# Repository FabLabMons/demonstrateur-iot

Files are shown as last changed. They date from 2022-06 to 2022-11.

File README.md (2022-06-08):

# Click IoT Board
## Purpose
This board aims to provide a starting point for building LTE Cat 1 projects for collecting data from a range of sensors.
These sensors can be connected on the I2C and SPI interfaces via a 4-wires connector.
Sensor boards will be hosted on a separate repository.

## Miscellaneous
We use the open source CAD tool KiCAD to build our boards: https://www.kicad.org/

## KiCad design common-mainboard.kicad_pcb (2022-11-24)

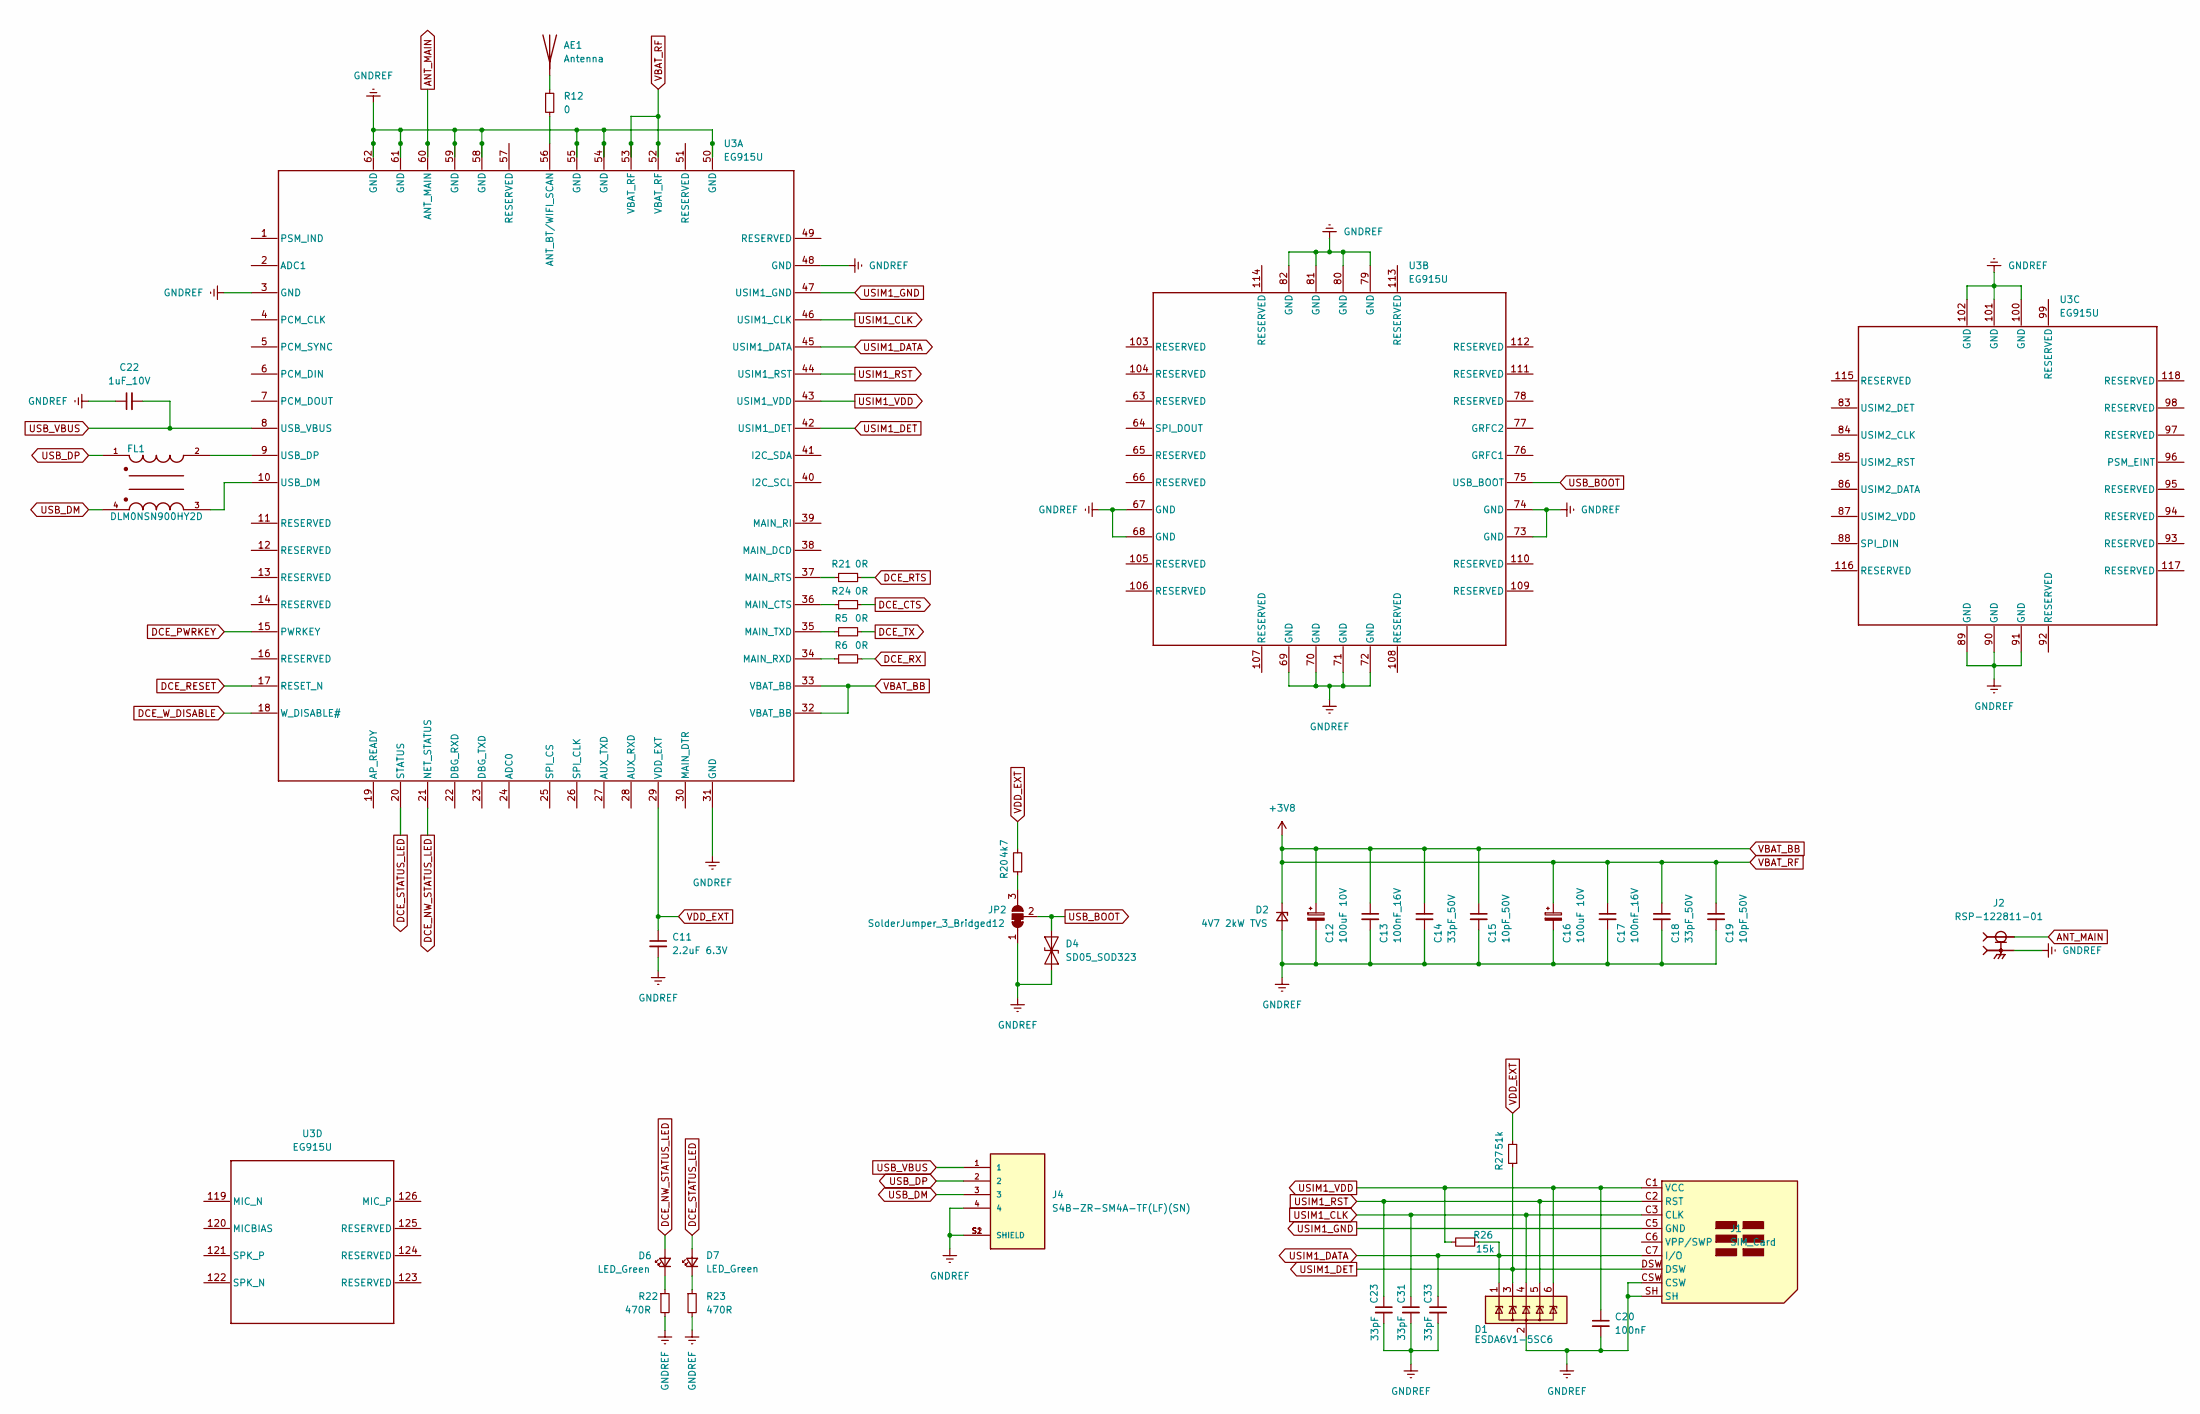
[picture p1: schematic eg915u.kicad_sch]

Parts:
AE1: Antenna; Quectel_YC0010AA
C11: 2.2uF 6.3V; C_0603_1608Metric
C12, C16: 100uF 10V; C_0603_1608Metric
C13, C17: 100nF_16V; C_0402_1005Metric
C14, C18: 33pF_50V; C_0402_1005Metric
C15, C19: 10pF_50V; C_0402_1005Metric
C20: 100nF; C_0402_1005Metric
C22: 1uF_10V; C_0603_1608Metric
C23, C31, C33: 33pF; C_0402_1005Metric
D1: ESDA6V1-5SC6; SOT-23-6
D2: 4V7 2kW TVS; D_SOD-323
D4: SD05_SOD323; D_SOD-323
D6, D7: LED_Green; LED_0805_2012Metric
FL1: DLM0NSN900HY2D; FIL_DLM0NSN900HY2D; PARTREV N/A
J1: SIM_Card; JAE_SIM_Card_SF72S006
J2: RSP-122811-01; SAMTEC_RSP-122811-01; PARTREV H
J4: S4B-ZR-SM4A-TF(LF)(SN); JST_S4B-ZR-SM4A-TF(LF)(SN); PARTREV N/A
JP2: SolderJumper_3_Bridged12; SolderJumper-3_P1.3mm_Bridged12_RoundedPad1.0x1.5mm
R5, R6, R21, R24: 0R; R_0402_1005Metric
R12: 0; R_0402_1005Metric
R20: 4k7; R_0402_1005Metric
R22, R23: 470R; R_0402_1005Metric
R26: 15k; R_0402_1005Metric
R27: 51k; R_0402_1005Metric
U3: EG915U; _AD LIB_EG915U.PcbLib_EG915U

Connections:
ANT_MAIN: J2.1, U3.60 (ANT_MAIN)
DCE_CTS: R24.2; also elsewhere on the board
DCE_NW_STATUS_LED: D6.2 (A), U3.21 (NET_STATUS)
DCE_PWRKEY: U3.15 (PWRKEY); also elsewhere on the board
DCE_RESET: U3.17 (RESET_N); also elsewhere on the board
DCE_RTS: R21.2; also elsewhere on the board
DCE_RX: R6.2; also elsewhere on the board
DCE_STATUS_LED: D7.2 (A), U3.20 (STATUS)
DCE_TX: R5.2; also elsewhere on the board
DCE_W_DISABLE: U3.18 (W_DISABLE#); also elsewhere on the board
GNDREF: C11.2, C12.2, C13.2, C14.2, C15.2, C16.2, C17.2, C18.2, C19.2, C20.2, C22.1, C23.2, C31.2, C33.2, D1.2 (GND), D2.2 (A), D4.2 (A2), J1.CSW, J1.SH, J2.G1, J2.G2, J4.4, J4.S1 (SHIELD), J4.S2 (SHIELD), JP2.1 (A), R22.2, R23.2, U3.3 (GND), U3.31 (GND), U3.48 (GND), U3.50 (GND), U3.54 (GND), U3.55 (GND), U3.58 (GND), U3.59 (GND), U3.61 (GND), U3.62 (GND), U3.67 (GND), U3.68 (GND), U3.69 (GND), U3.70 (GND), U3.71 (GND), U3.72 (GND), U3.73 (GND), U3.74 (GND), U3.79 (GND), U3.80 (GND), U3.81 (GND), U3.82 (GND), U3.89 (GND), U3.90 (GND), U3.91 (GND), U3.100 (GND), U3.101 (GND), U3.102 (GND); also elsewhere on the board
unnamed: AE1.1 (A), R12.1
unnamed: D6.1 (K), R22.1
unnamed: D7.1 (K), R23.1
unnamed: FL1.2, U3.9 (USB_DP)
unnamed: FL1.3, U3.10 (USB_DM)
unnamed: JP2.3 (B), R20.1
unnamed: R5.1, U3.35 (MAIN_TXD)
unnamed: R6.1, U3.34 (MAIN_RXD)
unnamed: R12.2, U3.56 (ANT_BT/WIFI_SCAN)
unnamed: R21.1, U3.37 (MAIN_RTS)
unnamed: R24.1, U3.36 (MAIN_CTS)
USB_BOOT: D4.1 (A1), JP2.2 (C), U3.75 (USB_BOOT)
USB_DM: FL1.4, J4.3
USB_DP: FL1.1, J4.2
USB_VBUS: C22.2, J4.1, U3.8 (USB_VBUS)
USIM1_CLK: C31.1, D1.4 (IO3), J1.C3 (CLK), U3.46 (USIM1_CLK)
USIM1_DATA: C33.1, D1.1 (IO1), J1.C7 (I/O), R26.1, U3.45 (USIM1_DATA)
USIM1_DET: D1.3 (IO2), J1.DSW, R27.1, U3.42 (USIM1_DET)
USIM1_GND: J1.C5 (GND), U3.47 (USIM1_GND)
USIM1_RST: C23.1, D1.5 (IO4), J1.C2 (RST), U3.44 (USIM1_RST)
USIM1_VDD: C20.1, D1.6 (IO5), J1.C1 (VCC), R26.2, U3.43 (USIM1_VDD)
VBAT_BB: C12.1, C13.1, C14.1, C15.1, C16.1, C17.1, C18.1, C19.1, D2.1 (K), U3.32 (VBAT_BB), U3.33 (VBAT_BB), U3.52 (VBAT_RF), U3.53 (VBAT_RF); also elsewhere on the board
VDD_EXT: C11.1, R20.2, R27.2, U3.29 (VDD_EXT); also elsewhere on the board

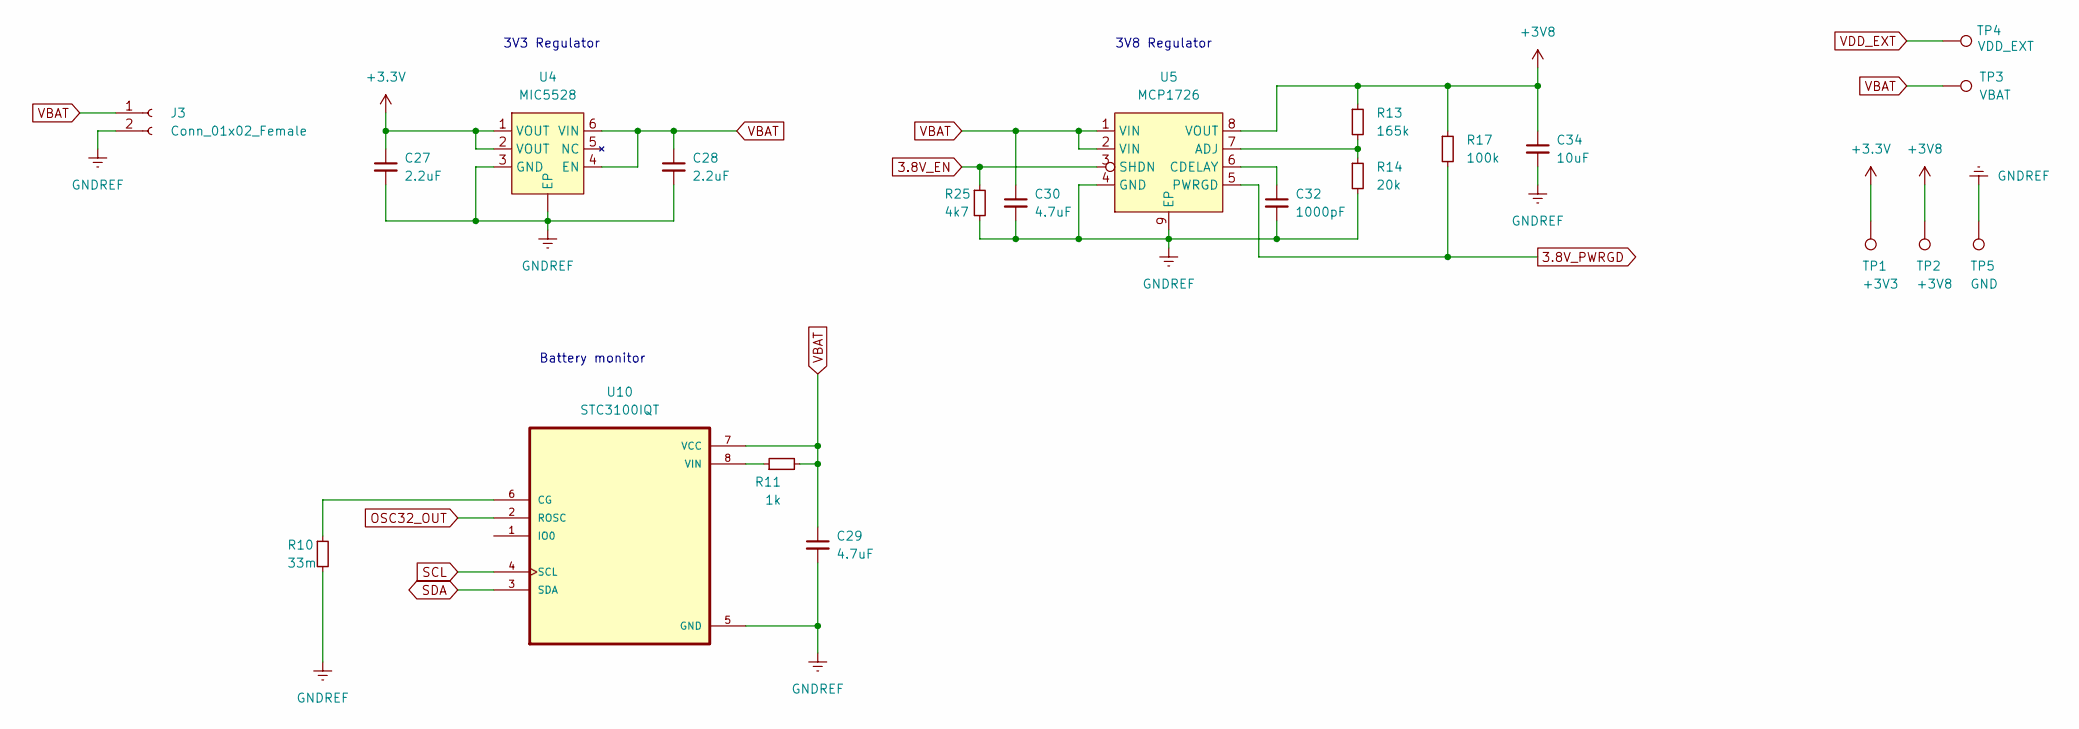
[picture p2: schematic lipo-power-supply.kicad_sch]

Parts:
C27, C28: 2.2uF; C_0603_1608Metric
C29, C30: 4.7uF; C_0603_1608Metric
C32: 1000pF; C_0201_0603Metric
C34: 10uF; C_0603_1608Metric
J3: Conn_01x02_Female; JST_PH_B2B-PH-SM4-TB_1x02-1MP_P2.00mm_Vertical
R10: 33m; R_0402_1005Metric
R11: 1k; R_0402_1005Metric
R13: 165k; R_0402_1005Metric
R14: 20k; R_0402_1005Metric
R17: 100k; R_0402_1005Metric
R25: 4k7; R_0402_1005Metric
TP1: +3V3; TestPoint_Pad_D1.5mm
TP2: +3V8; TestPoint_Pad_D1.5mm
TP3: VBAT; TestPoint_Pad_D1.5mm
TP4: VDD_EXT; TestPoint_Pad_D1.5mm
TP5: GND; TestPoint_Pad_D1.5mm
U4: MIC5528; DFN-6-1EP_1.2x1.2mm_P0.4mm_EP0.3x0.94mm_PullBack
U5: MCP1726; DFN-8-1EP_3x3mm_P0.65mm_EP1.55x2.4mm
U10: STC3100IQT; DFN-8-1EP_3x3mm_P0.5mm_EP1.65x2.38mm

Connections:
3.8V_EN: R25.1, U5.3 (SHDN); also elsewhere on the board
3.8V_PWRGD: R17.2, U5.5 (PWRGD); also elsewhere on the board
+3V3: C27.1, TP1.1, U4.1 (VOUT), U4.2 (VOUT); also elsewhere on the board
GNDREF: C27.2, C28.2, C29.2, C30.2, C32.2, C34.2, J3.2, R10.2, R14.2, R25.2, TP5.1, U4. (EP), U4.3 (GND), U5.4 (GND), U5.9 (EP), U10.5 (GND); also elsewhere on the board
unnamed: C32.1, U5.6 (CDELAY)
unnamed: R10.1, U10.6 (CG)
unnamed: R11.1, U10.8 (VIN)
unnamed: R13.2, R14.1, U5.7 (ADJ)
OSC32_OUT: U10.2 (ROSC); also elsewhere on the board
SCL: U10.4 (SCL); also elsewhere on the board
SDA: U10.3 (SDA); also elsewhere on the board
VBAT: C28.1, C29.1, C30.1, J3.1, R11.2, TP3.1, U4.4 (EN), U4.6 (VIN), U5.1 (VIN), U5.2 (VIN), U10.7 (VCC)
VBAT_BB: C34.1, R13.1, R17.1, TP2.1, U5.8 (VOUT); also elsewhere on the board
VDD_EXT: TP4.1; also elsewhere on the board

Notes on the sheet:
Battery monitor
3V8 Regulator
3V3 Regulator

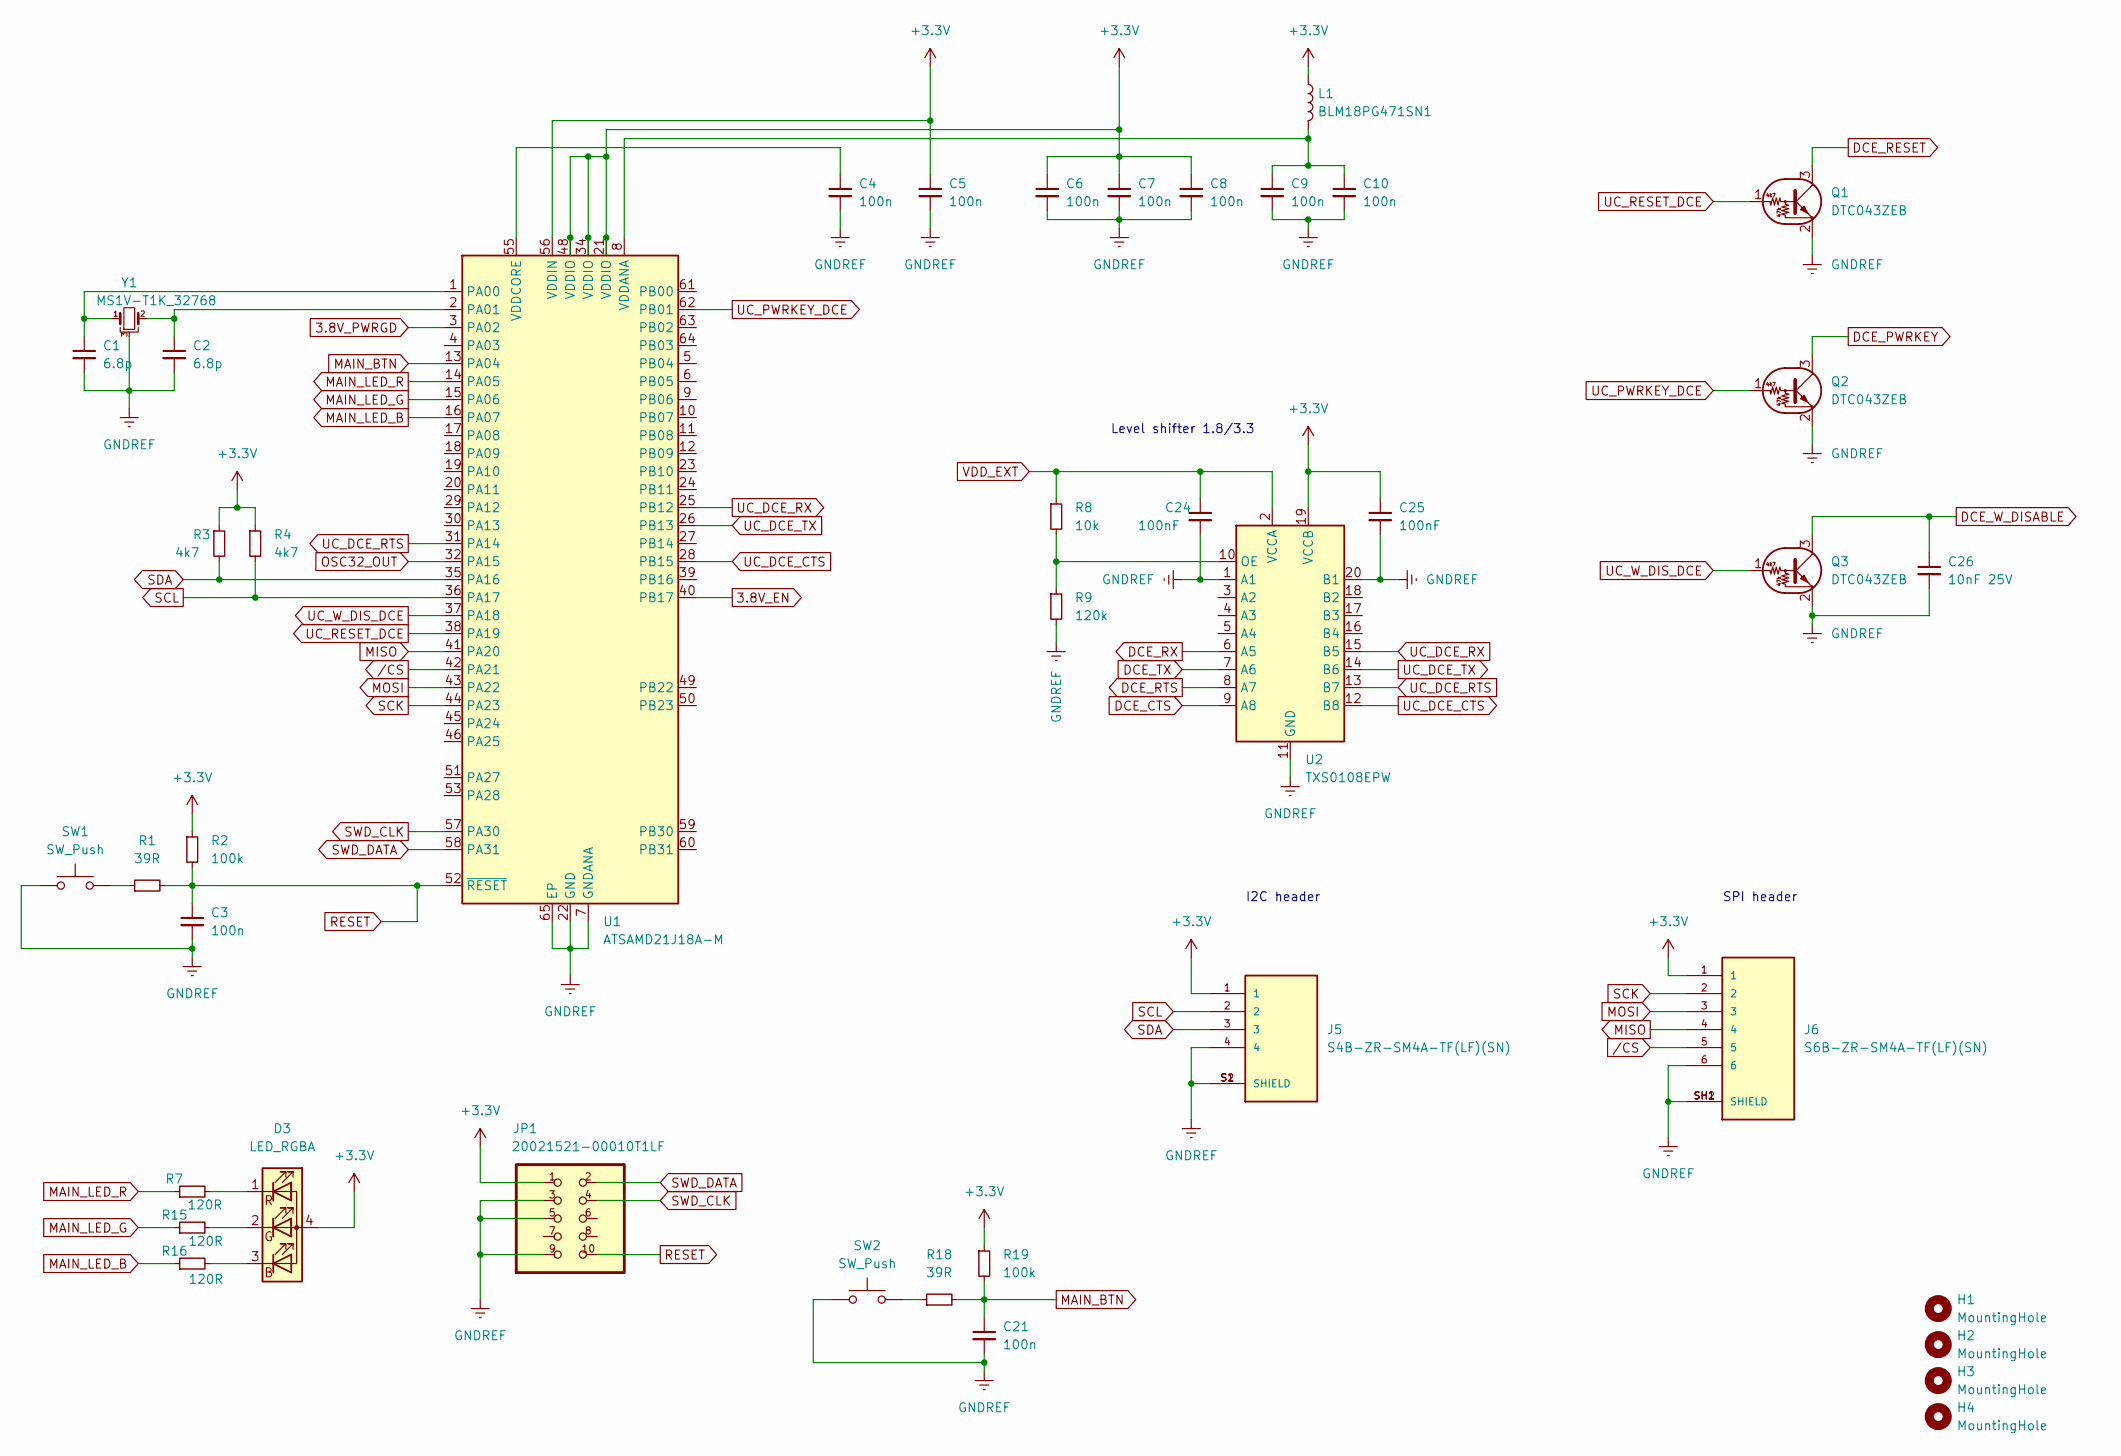
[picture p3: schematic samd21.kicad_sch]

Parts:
C1, C2: 6.8p; C_0402_1005Metric
C3, C4, C5, C6, C7, C8, C9, C10, C21: 100n; C_0402_1005Metric
C24, C25: 100nF; C_0402_1005Metric
C26: 10nF 25V; C_0402_1005Metric
D3: LED_RGBA; LED_RGB_Wuerth-PLCC4_3.2x2.8mm_150141M173100
H1, H2, H3, H4: MountingHole; MountingHole_3.2mm_M3
J5: S4B-ZR-SM4A-TF(LF)(SN); JST_S4B-ZR-SM4A-TF(LF)(SN); PARTREV N/A
J6: S6B-ZR-SM4A-TF(LF)(SN); JST_S6B-ZR-SM4A-TF(LF)(SN)
JP1: 20021521-00010T1LF
L1: BLM18PG471SN1; C_0603_1608Metric
Q1, Q2, Q3: DTC043ZEB; SOT-416
R1, R18: 39R; R_0402_1005Metric
R2, R19: 100k; R_0402_1005Metric
R3, R4: 4k7; R_0402_1005Metric
R7, R15, R16: 120R; R_0402_1005Metric
R8: 10k; R_0402_1005Metric
R9: 120k; R_0402_1005Metric
SW1, SW2: SW_Push; SW_SPST_CK_KXT3
U1: ATSAMD21J18A-M; QFN-64-1EP_9x9mm_P0.5mm_EP4.7x4.7mm
U2: TXS0108EPW; TSSOP-20_4.4x6.5mm_P0.65mm
Y1: MS1V-T1K_32768; Crystal_SMD_MicroCrystal_MS1V-T1K

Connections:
3.8V_EN: U1.40 (PB17); also elsewhere on the board
3.8V_PWRGD: U1.3 (PA02); also elsewhere on the board
+3V3: C5.1, C6.1, C7.1, C8.1, C25.1, D3.4 (A), J5.1, J6.1, JP1.1, L1.1, R2.1, R3.1, R4.1, R19.1, U1.21 (VDDIO), U1.34 (VDDIO), U1.48 (VDDIO), U1.56 (VDDIN), U2.19 (VCCB); also elsewhere on the board
DCE_CTS: U2.9 (A8); also elsewhere on the board
DCE_PWRKEY: Q2.3 (C); also elsewhere on the board
DCE_RESET: Q1.3 (C); also elsewhere on the board
DCE_RTS: U2.8 (A7); also elsewhere on the board
DCE_RX: U2.6 (A5); also elsewhere on the board
DCE_TX: U2.7 (A6); also elsewhere on the board
DCE_W_DISABLE: C26.1, Q3.3 (C); also elsewhere on the board
GNDREF: C1.2, C2.2, C3.2, C4.2, C5.2, C6.2, C7.2, C8.2, C9.2, C10.2, C21.2, C24.2, C25.2, C26.2, J5.4, J5.S1 (SHIELD), J5.S2 (SHIELD), J6.6, J6.SH1 (SHIELD), J6.SH2 (SHIELD), JP1.3, JP1.5, JP1.9, Q1.2 (E), Q2.2 (E), Q3.2 (E), R9.2, SW1.1, SW2.1, U1.7 (GNDANA), U1.22 (GND), U1.33 (GND), U1.47 (GND), U1.54 (GND), U1.65 (EP), U2.1 (A1), U2.11 (GND), U2.20 (B1), Y1.3; also elsewhere on the board
MAIN_BTN: C21.1, R18.2, R19.2, U1.13 (PA04)
MAIN_LED_B: R16.1, U1.16 (PA07)
MAIN_LED_G: R15.1, U1.15 (PA06)
MAIN_LED_R: R7.1, U1.14 (PA05)
MISO: J6.4, U1.41 (PA20)
MOSI: J6.3, U1.43 (PA22)
unnamed: C1.1, U1.1 (PA00), Y1.1
unnamed: C2.1, U1.2 (PA01), Y1.2
unnamed: C4.1, U1.55 (VDDCORE)
unnamed: C9.1, C10.1, L1.2, U1.8 (VDDANA)
unnamed: D3.1 (RK), R7.2
unnamed: D3.2 (GK), R15.2
unnamed: D3.3 (BK), R16.2
unnamed: R1.1, SW1.2
unnamed: R8.2, R9.1, U2.10 (OE)
unnamed: R18.1, SW2.2
OSC32_OUT: U1.32 (PA15); also elsewhere on the board
RESET: C3.1, JP1.10, R1.2, R2.2, U1.52 (~RESET)
SCK: J6.2, U1.44 (PA23)
SCL: J5.2, R4.2, U1.36 (PA17); also elsewhere on the board
SDA: J5.3, R3.2, U1.35 (PA16); also elsewhere on the board
SWD_CLK: JP1.4, U1.57 (PA30)
SWD_DATA: JP1.2, U1.58 (PA31)
UC_DCE_CTS: U1.28 (PB15), U2.12 (B8)
UC_DCE_RTS: U1.31 (PA14), U2.13 (B7)
UC_DCE_RX: U1.25 (PB12), U2.15 (B5)
UC_DCE_TX: U1.26 (PB13), U2.14 (B6)
UC_PWRKEY_DCE: Q2.1 (B), U1.62 (PB01)
UC_RESET_DCE: Q1.1 (B), U1.38 (PA19)
UC_W_DIS_DCE: Q3.1 (B), U1.37 (PA18)
VDD_EXT: C24.1, R8.1, U2.2 (VCCA); also elsewhere on the board
/CS: J6.5, U1.42 (PA21)

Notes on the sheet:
I2C header
Level shifter 1.8/3.3
SPI header

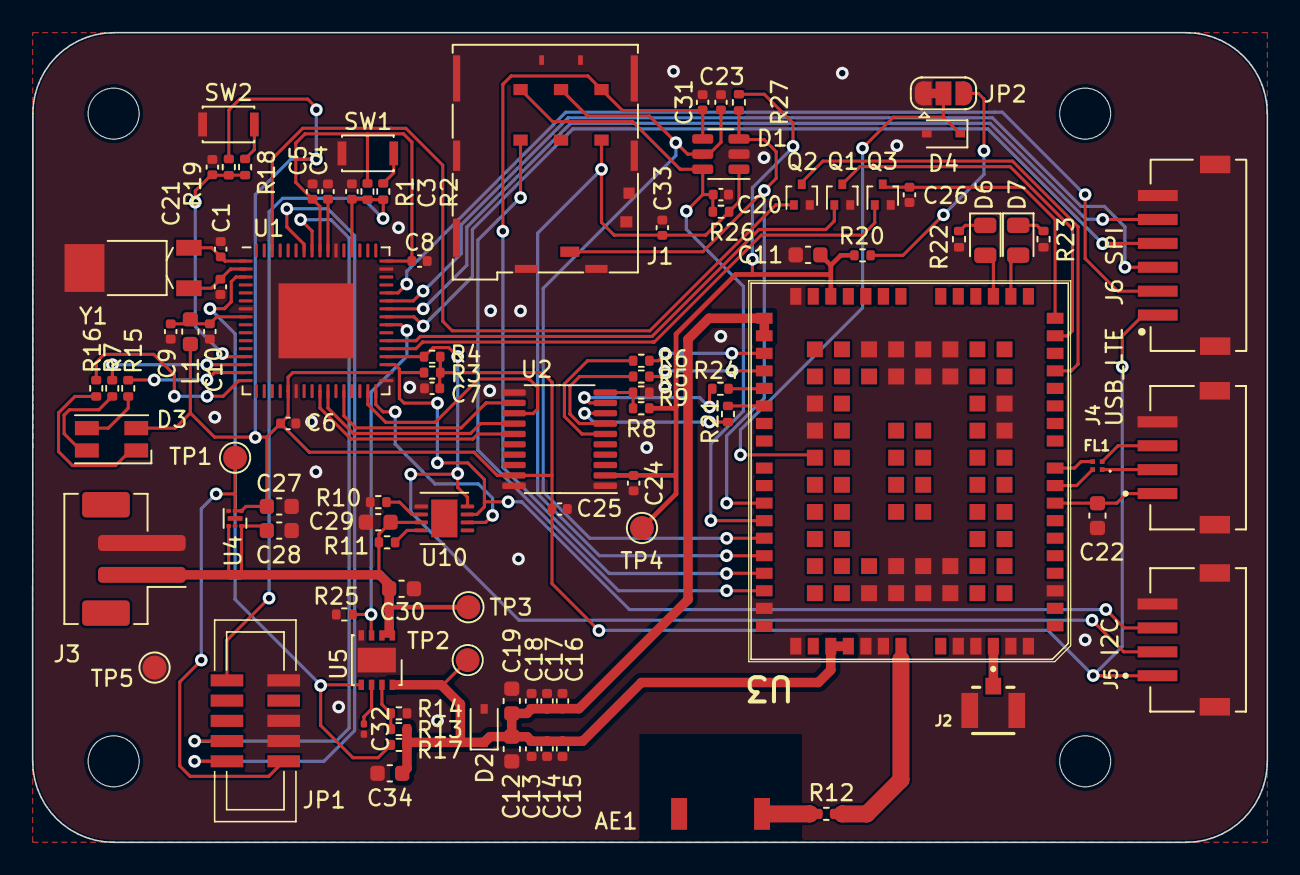
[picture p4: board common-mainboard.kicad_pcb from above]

Board: 2 copper layers, 77.5 x 50.8 mm, 99 parts (0 on the bottom side), 73 nets.

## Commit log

2022-09-21 eg915u: modified page layout, added USB upgrade support (sch + pcb)
    [common-mainboard.kicad_pcb, common-mainboard.kicad_sch, eg915u.kicad_sch]
2022-09-21 added UART flow control pins CTS and RTS
    [common-mainboard.kicad_pcb, common-mainboard.kicad_sch, eg915u.kicad_sch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]
2022-09-21 added test point for VDD_EXT
    [common-mainboard.kicad_pcb, common-mainboard.kicad_sch, lipo-power-supply.kicad_sch]
2022-09-21 3.8V LDO: added output enable control from uc
    [common-mainboard.kicad_pcb, common-mainboard.kicad_sch, eg915u.kicad_sch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]
2022-09-21 sim card: added RF filtering passive components
    [common-mainboard.kicad_pcb, common-mainboard.kicad_sch, eg915u.kicad_sch]
2022-09-28 added connectors for I2C and SPI extensions
    [common-mainboard.kicad_pcb, common-mainboard.kicad_sch, eg915u.kicad_sch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]
2022-10-13 updated footprints and PCB
    [common-mainboard.kicad_pcb, common-mainboard.kicad_sch, eg915u.kicad_sch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]
2022-10-14 fixed SIM card orientation
    [common-mainboard.kicad_pcb]
2022-10-14 [FAB] added board dimensions
    [common-mainboard.kicad_pcb]
2022-11-24 PCB: moved vias from underneath to outside of ICs
    [common-mainboard.kicad_pcb]
